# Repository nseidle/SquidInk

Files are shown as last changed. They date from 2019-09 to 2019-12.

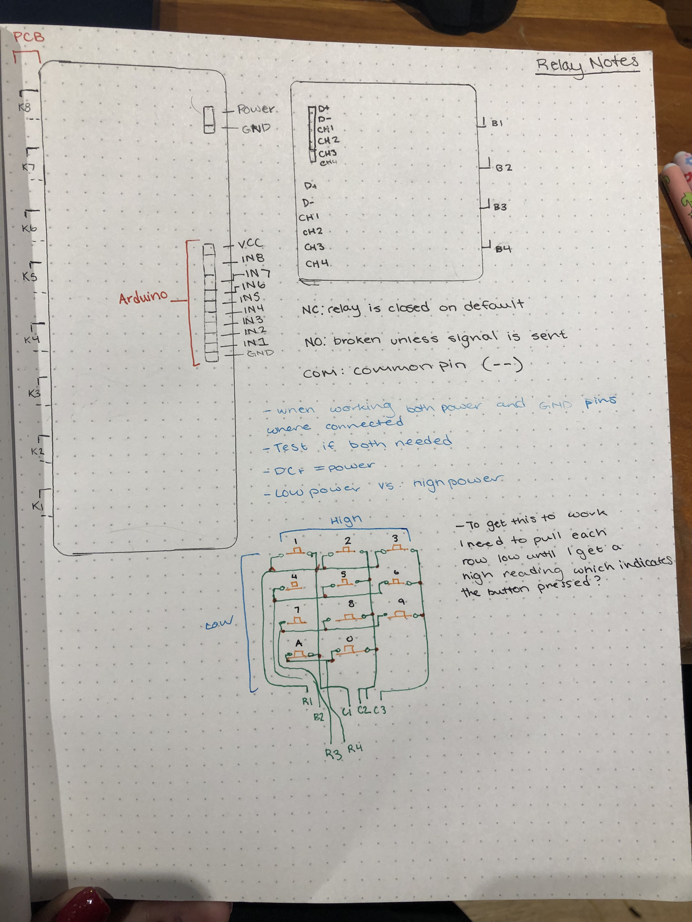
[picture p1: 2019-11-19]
relay-schematic/IMG_3992.jpg

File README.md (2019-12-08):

# SquidInk
Stalwart Keypad Safe Cracking Robot
Why are we doing this?
This project of attempting to crack into the stalwart safe is not only legal, it's teachable. We are being taught how to seek out the vulnerabilities in the keypad safe using various methods and contructing robots to do so. 

Here is the website with full documentation:

https://claire0sutton.wordpress.com/category/safecracking/

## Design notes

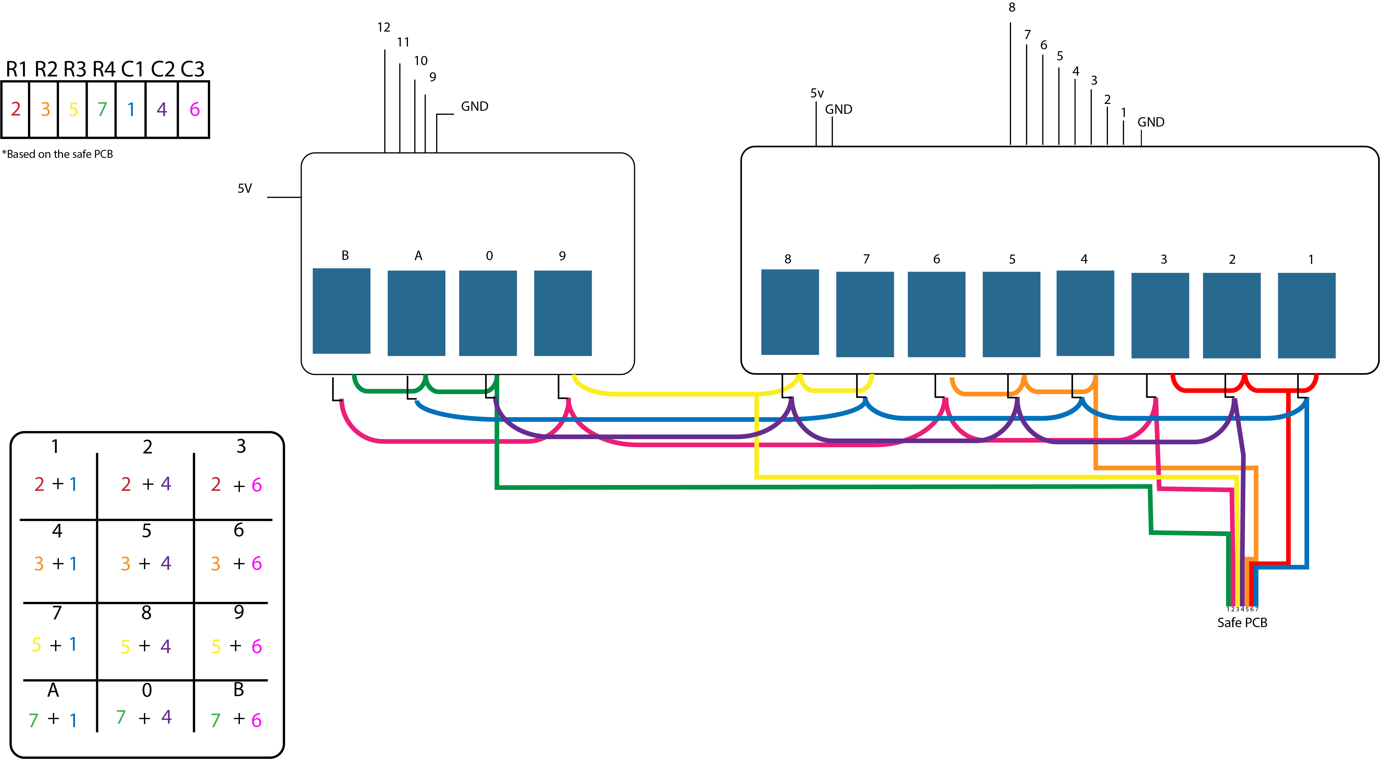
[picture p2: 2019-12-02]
relay-schematic/relay-switch-schematic.jpg

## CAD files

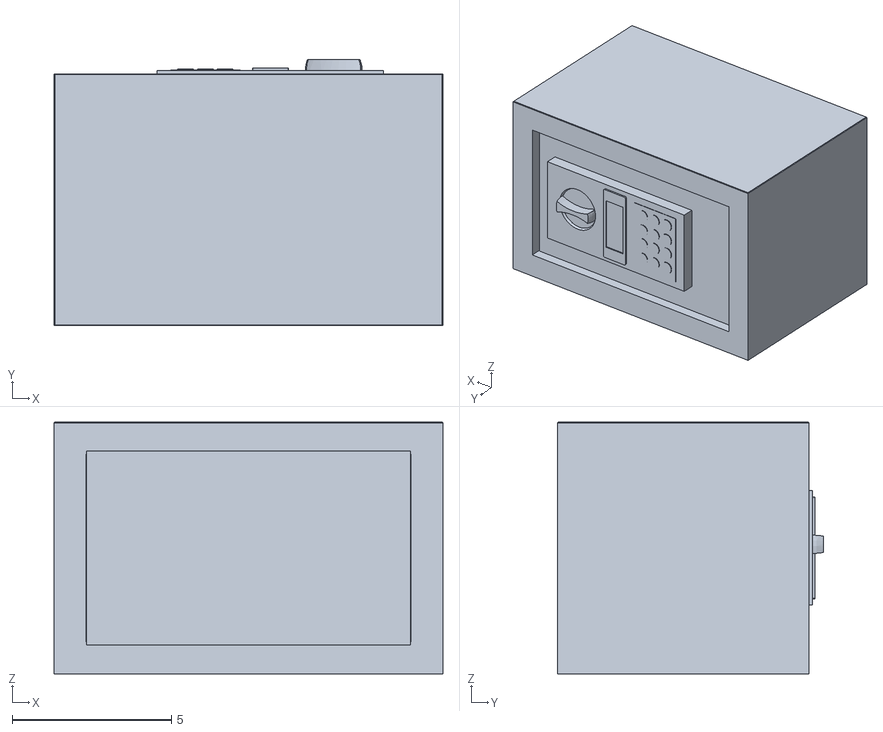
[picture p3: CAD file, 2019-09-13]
3D-models/safemodel.stl
12.2 x 8.39 x 7.90

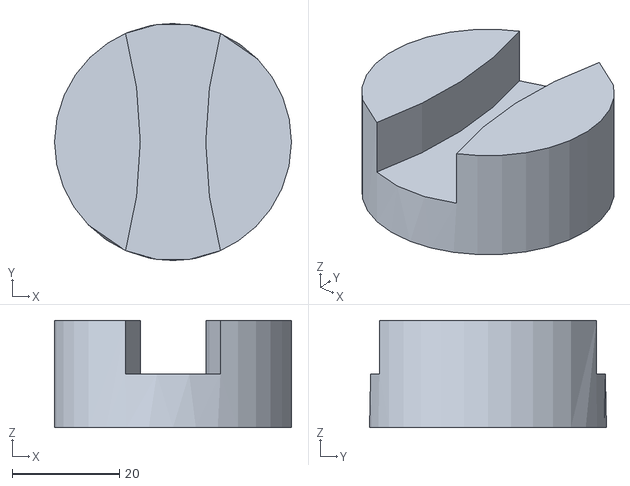
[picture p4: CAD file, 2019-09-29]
handle-puller-files/dial_coupler_bigger.stl
44.2 x 44.2 x 20.0

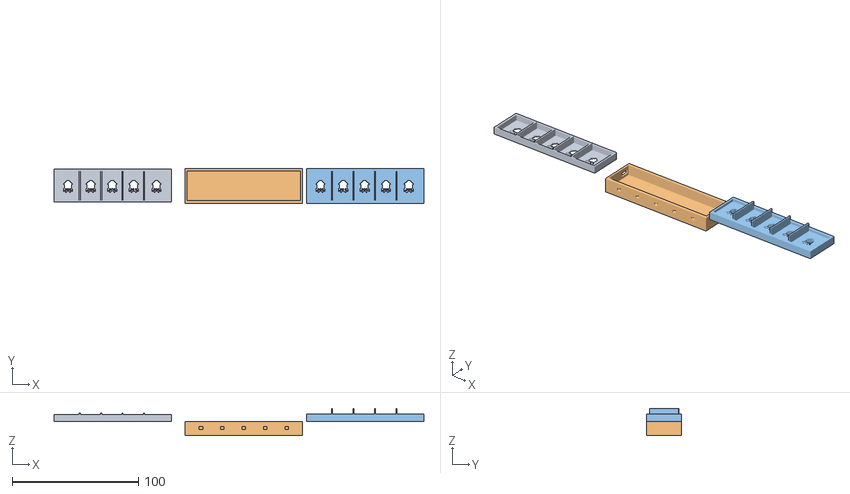
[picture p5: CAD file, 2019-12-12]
squid v10.obj
293.2 x 28.1 x 21.5

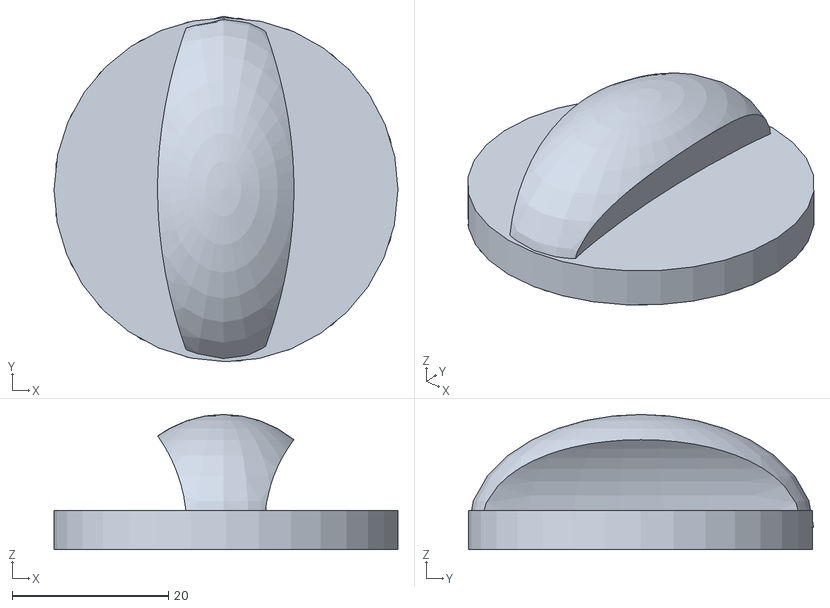
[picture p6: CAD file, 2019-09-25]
handle-puller-files/dial.stl
44.0 x 44.2 x 17.3

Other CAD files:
3D-models/The Safe v2.f3d
dial.3dm

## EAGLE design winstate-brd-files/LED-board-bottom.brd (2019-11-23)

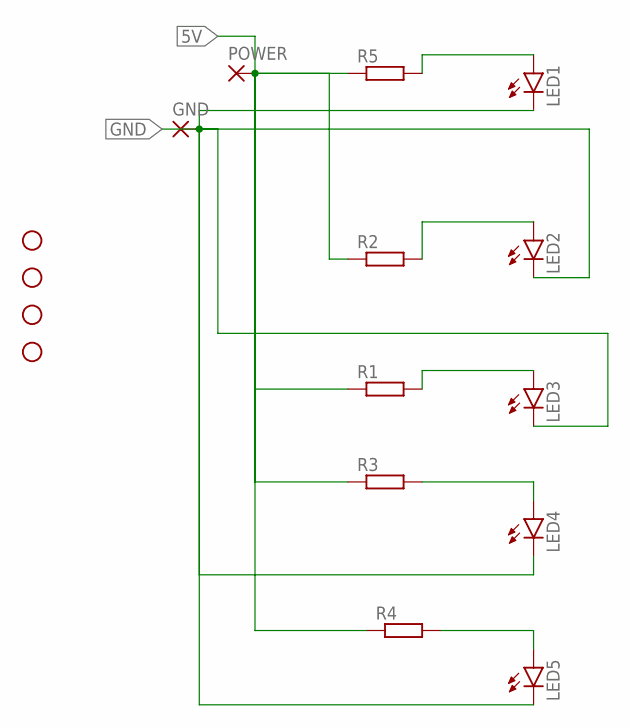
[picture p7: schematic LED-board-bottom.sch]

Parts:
GND: 1,6/0,8
H1, H2, H3, H4: STAND-OFF
LED1, LED2, LED3, LED4, LED5: LED3MM
POWER: 1,6/0,8
R1, R2, R3, R4, R5: R-EU_0207/10; 0207/10

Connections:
5V: POWER.1, R1.1, R2.1, R3.1, R4.1, R5.1
GND: GND.1, LED1.K (C), LED2.K (C), LED3.K (C), LED4.K (C), LED5.K (C)
unnamed: LED1.A, R5.2
unnamed: LED2.A, R2.2
unnamed: LED4.A, R3.2
unnamed: LED5.A, R4.2
unnamed: LED3.A, R1.2

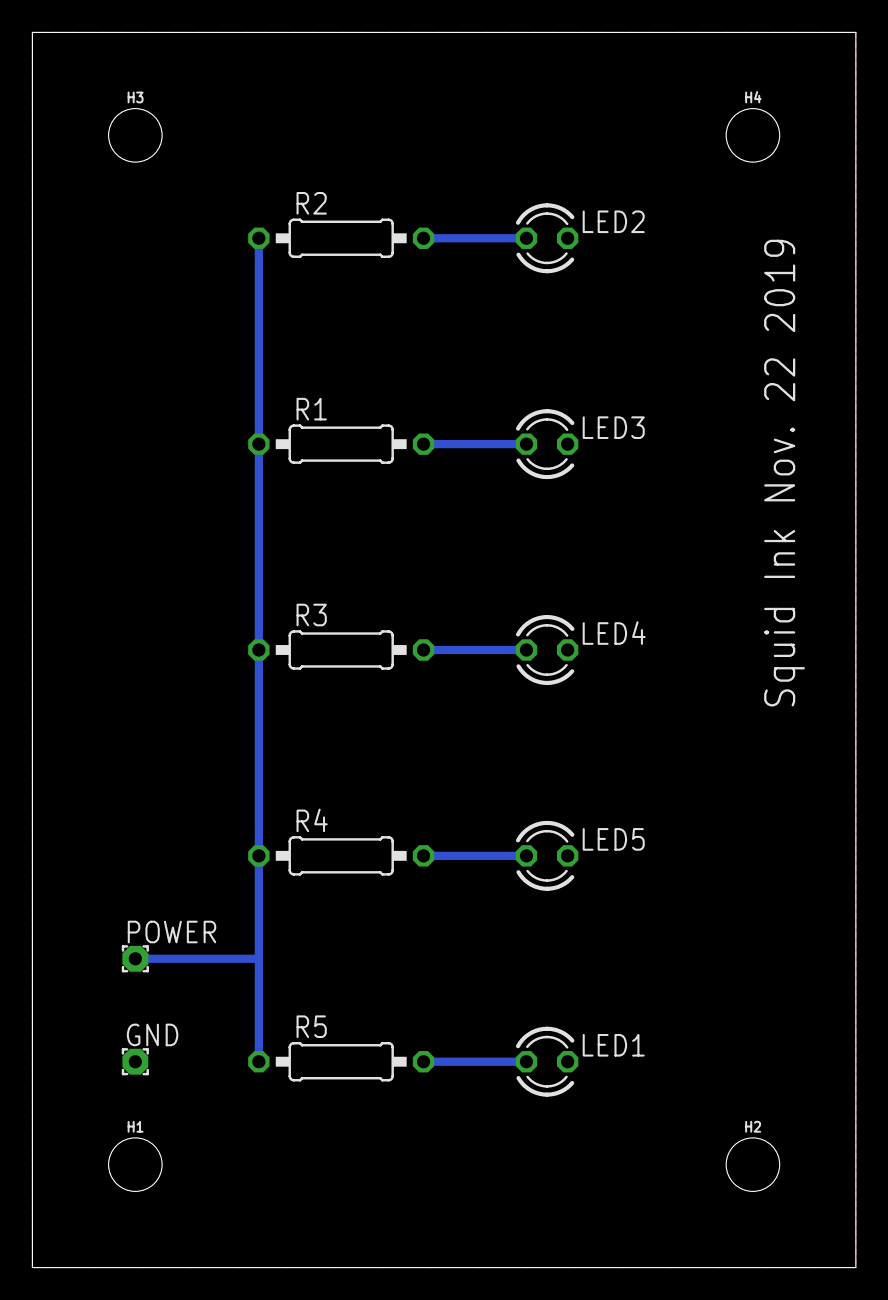
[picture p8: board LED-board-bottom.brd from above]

Board: 2 copper layers, 50.8 x 76.2 mm, 16 parts (0 on the bottom side), 7 nets.

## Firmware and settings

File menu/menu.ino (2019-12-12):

//created by Lili Cushing-Quevli
//modified: December 11th, 2019

//DESIGNED TO WORK WITH A 3 DIGIT CODE
//simulate pressing of buttons with a switch menu
//take user input and then properly press keys
//store winning value in EEPROM if using loop sequence function (can be unplugged from computer at this point)
//otherwise prints to serial monitor when winning code is found

#include <EEPROM.h>

//****RELAYS*****
int relay1 = 13;
int relay2 = 2;
int relay3 = 3;
int relay4 = 4;
int relay5 = 5;
int relay6 = 6;
int relay7 = 7;
int relay8 = 8;
int relay9 = 9;
int relay0 = 10;
int EnterA = 11;

int readResistor;

//*******LEDS**************
int LED1 = A5;
int LED2 = A4;
int LED3 = A3;
int LED4 = A2;
int LED5 = A1;




int photoResistor = A0;

int delayTime = 114;

//can go up to 3 codes before needing delay sequence called.
int timeOut = 1;

//used in the menu, typesetting
float reading = 0;
//array of all of manually entered values
float testedComboArray[2];
int randSelectCombo[1000];
//keep track of which value in the array is free :)
int increment = 0;
//entered code, set with returned value. If it's -1, something's wrong
int codeLength = 0;
//used in loopSequence function
int comboArray[3] = {0, 0, 0};
int winCodeArray[3] = {0, 0, 0};

//*****SERVO MOTOR********
//position of motor
//optional, currently commented out. For usage with the 3D printed handle cover and a servo motor (included in GH repo)
int pos = 0;
int servoPin = 12;

void setup()
{

  pinMode(relay1, OUTPUT);
  pinMode(relay2, OUTPUT);
  pinMode(relay3, OUTPUT);
  pinMode(relay4, OUTPUT);
  pinMode(relay5, OUTPUT);
  pinMode(relay6, OUTPUT);
  pinMode(relay7, OUTPUT);
  pinMode(relay8, OUTPUT);
  pinMode(relay9, OUTPUT);
  pinMode(relay0, OUTPUT);
  pinMode(EnterA, OUTPUT);

  //all relay switches are set to HIGH to be set LOW later when a button needs pressed
  digitalWrite(relay1, HIGH);
  digitalWrite(relay2, HIGH);
  digitalWrite(relay3, HIGH);
  digitalWrite(relay4, HIGH);
  digitalWrite(relay5, HIGH);
  digitalWrite(relay6, HIGH);
  digitalWrite(relay7, HIGH);
  digitalWrite(relay8, HIGH);
  digitalWrite(relay9, HIGH);
  digitalWrite(relay0, HIGH);
  digitalWrite(EnterA, HIGH);

  //fill the random combo array with values from 0-999
  int beginningIncrement = 0;
  for (int i = 0; i < 1000; i++)
  {
    randSelectCombo[i] = i;
  }


  Serial.begin(9600);

  //menu only prints once
  printMenu();


}

void loop() {

  //credit to Nathan Seidle for help with the code + lecture on serial.available
  while (Serial.available() > 0)
  {

    //if there's something to read, do something

    reading = Serial.read();

    if (reading == '\n') {
      Serial.print("\n");

    }

    //Serial.println(reading);
    //Didn't want to do ACII, so we do char reading instead
    if (reading == '1')
    {
      //sets EEMPROM code starting point
      startCombo();


    }

    else if (reading == '2')
    {
      //takes input from serial monitor and enters in correct buttons
      manualEnter();

    }

    else if (reading == '3')
    {
      //starts from EEPROM value, then increments in order, by going up one digit at a time
      loopSequence();

    }

    else if (reading == '4')
    {
      //set the combo
      startCombo();


    }

    else if (reading == '5')
    {
      //retrieve stored EEPROM win value once winState is triggered
      retrieveWinCode();

    }


    else
    {
      //don't do anything

    }


  }


}

void printMenu()
{
  Serial.println("Cracking a Keypad Safe, Choose an option");
  Serial.println("******When the safe combo is found, the squids will light up*******");
  Serial.println("1. Set starting code");
  Serial.println("2. Manually enter a code");
  Serial.println("3. Start loop sequence");
  Serial.println("4. Set Code Manually");
  Serial.println("5. Retrieve Win Code :)");


}


void manualEnter()
{
  delay(10);
  while (Serial.available() > 0)
  {

    //if there's something to read, take that number
    //save it in a value/ array
    //for now has an array of a large size, but could consider adding vector library, at the cost of memory
    //wait for carriage return

    while (Serial.available() > 0) {

      Serial.read();
      //clears out the buffer

    }

    Serial.println("ENTER THE COMBO (Do not use letters, please only 3 digits long)");
    while (Serial.available() == 0) {

      //Do nothing
    }
    while (Serial.available() > 0)
    {

      //if there's something to read, take that number
      //make it the length

      int testCombo = Serial.parseInt();
      Serial.print("The combo you've entered is: ");
      Serial.println(testCombo);

      //code citation
      //by Christop
      //source link: https://forum.arduino.cc/index.php?topic=307479.0
      //parses the full code entered and separates it into individual numbers
      unsigned n = testCombo;
      unsigned firstVal = (n / 100U) % 10;
      unsigned secondVal = (n / 10U) % 10;
      unsigned thirdVal = (n / 1U) % 10;

      //      Serial.println(firstVal);
      //      Serial.println(secondVal);
      //      Serial.println(thirdVal);
      //

      //press the numbers entered
      pressNumber(firstVal);
      pressNumber(secondVal);
      pressNumber(thirdVal);
      pressEnter();
      //Serial.println("Checking Winstate: ");
      bool testWin = winState();



      if (testWin == true)
      {
        Serial.print("Congratulations, you've entered the right combo. Your Combo is: ");
        Serial.print(firstVal);
        Serial.print(", ");
        Serial.print(secondVal);
        Serial.print(", ");
        Serial.println(thirdVal);

      }

      return;


    }




  }


}

void loopSequence()
{
  Serial.println("Sequence of all possible combos is about to begin");
  Serial.println("Combo array is:");

  bool found = 0;


  int addrTest = 0;
  int comboVal;

  //the 7th value is a boolean to determine if it was ever run (w/o a board reset) that way, we can fill in 
  //the values, if they exist
  if (EEPROM.read(7) == 1)
  {
    Serial.println("There was something previously stored here...");
    for (int j = 0; j < 3; j++)
    {
      comboVal = EEPROM.read(addrTest);
      addrTest += 2;

      Serial.print(comboVal, DEC);


      comboArray[j] = comboVal;

    }
  }
  Serial.print("\n");

  while (found == 0)
  {

    //by default, array is set to have all zeros
    //start with 0,0,0 and then increment the last value, going until the last value hits the tenth value
    //increment the second value and start the for loop again



    for (int i = comboArray[2]; i < 10; i++)
    {
      //call switch case menu to execute the pressing of the buttons


      pressNumber(comboArray[0]);

      pressNumber(comboArray[1]);

      pressNumber(i);



      pressEnter();
      Serial.print(comboArray[0]);
      Serial.print(",");
      Serial.print(comboArray[1]);
      Serial.print(",");
      Serial.println(i);

      addrTest = 0;

      for (int j = 0; j < 3; j++)
      {
        int writeCombo = 0;
        writeCombo = comboArray[j];
        EEPROM.write(addrTest, writeCombo);
        addrTest += 2;

      }



      if (winState())
      {
        Serial.println("WINNING CODE WAS:");

        Serial.print(comboArray[0]);
        Serial.print(",");
        Serial.print(comboArray[1]);
        Serial.print(",");
        Serial.println(i);
        int tracker = 8;

        //save in the secondary values of EEPROM, get in other function
        //int is 2 bytes, increment accordingly
        EEPROM.write(tracker, comboArray[0]);
        tracker += 2;
        EEPROM.write(tracker, comboArray[1]);
        tracker += 2;
        EEPROM.write(tracker, i);


        //        Serial.println("Congratulations, The correct combo has been found! Your Combo is: ");
        //        Serial.print(comboArray[0]);
        //        Serial.print(", ");
        //        Serial.print(comboArray[1]);
        //        Serial.print(", ");
        //        Serial.print(i);
        //        //turnHandle();
        //        Serial.println("Exiting function....");
        found = 1;
        break;
      }


      //every 3 combos, it requires a time out of 4 minutes and 46 seconds
      if (timeOut % 3 == 0)
      {
        stopSequence();
      }
      timeOut++;


    }

    //since the comboArray[2] was initially set with the EEPROM value, we now need to set it back to 0 when it starts the for loop again
    comboArray[2] = 0;

    //if the second combo does not have the value nine in it
    if (comboArray[1] < 9)
    {
      //move up one.
      //Example : instead of 0,0,0
      // it is now 0,1,[i]
      comboArray[1] += 1;


    }
    //on the 8th time, it will increment to 9 and then go through the for loop one last time with 9, then when it comes back
    //it is no longer less than 9, and will go to the next statement

    else
    {
      //if we have already gone through the second and third values with the current first value
      //and none worked, we increment the first value and try every possible value for the
      //second and third
      if (comboArray[1] >= 9)
      {
        comboArray[0] += 1;
        comboArray[1] = 0;
      }



    }


  }
  return;

}

void startCombo()
{
  delay(10);
  Serial.println("ENTER THE COMBO TO BEGIN LOOP (Do not use letters, please only 3 digits long)");
  while (Serial.available() > 0)
  {

    //if there's something to read, take that number
    //save it in a value/ array
    //for now has an array of a large size, but could consider adding vector library, at the cost of memory

    //wait for carriage return

    while (Serial.available() > 0) {

      Serial.read();
      //clears out the buffer

    }


    while (Serial.available() == 0) {

      //Do nothing
    }
    while (Serial.available() > 0)
    {

      //if there's something to read, take that number
      //make it the length

      int testCombo = Serial.parseInt();
      Serial.print("The combo you've entered is: ");
      Serial.println(testCombo);

      //code citation
      //by Christop
      //source link: https://forum.arduino.cc/index.php?topic=307479.0
      //parses the full code entered and separates it into individual numbers
      unsigned n = testCombo;
      unsigned firstVal = (n / 100U) % 10;
      unsigned secondVal = (n / 10U) % 10;
      unsigned thirdVal = (n / 1U) % 10;

      Serial.println("Setting the code....");
      int counting = 0;

      EEPROM.write(counting, firstVal );
      counting += 2;
      EEPROM.write(counting, secondVal);
      counting += 2;
      EEPROM.write(counting, thirdVal);

      EEPROM.write(7, 1);

      return;
    }
  }



}

void retrieveWinCode()
{
  Serial.println("Entered retrieve Win");

  int tracker = 8;
  int saver = 0;

  //get the EEPROM secondary values and then store in local array

  Serial.print("The Safes code is: ");
  saver = EEPROM.read(tracker);
  winCodeArray[0] = saver;


  tracker += 2;

  saver = EEPROM.read(tracker);
  winCodeArray[1] = saver;
  tracker += 2;

  saver = EEPROM.read(tracker);
  winCodeArray[2] = saver;

  Serial.print("YOUR WNNING CODE WAS: ");
  //print the array stored in EEPROM
  for (int i = 0; i < 3; i++)
  {

    Serial.print(winCodeArray[i]);

  }
  Serial.print("\n");



}

void resetCombo()
{
  delay(10);
  while (Serial.available() > 0)
  {

    //if there's something to read, take that number
    //save it in a value/ array
    //for now has an array of a large size, but could consider adding vector library, at the cost of memory
    //eeprom?
    //wait for carriage return

    while (Serial.available() > 0) {

      Serial.read();
      //clears out the buffer

    }

    Serial.println("Setting the Combo: Please enter your 3 digit Code you would like to set.");
    while (Serial.available() == 0) {

      //Do nothing
    }
    while (Serial.available() > 0)
    {

      //if there's something to read, take that number
      //make it the length

      int testCombo = Serial.parseInt();
      Serial.print("The combo you've entered is: ");
      Serial.println(testCombo);

      //code citation
      //by Christop
      //source link: https://forum.arduino.cc/index.php?topic=307479.0
      //parses the full code entered and separates it into individual numbers
      unsigned n = testCombo;
      unsigned firstVal = (n / 100U) % 10;
      unsigned secondVal = (n / 10U) % 10;
      unsigned thirdVal = (n / 1U) % 10;

      pressNumber(firstVal);
      pressNumber(secondVal);
      pressNumber(thirdVal);
      pressEnter();



      return;

    }
  }


}


//menu that takes a number passed into it and presses that number

void pressNumber( int var)
{
  switch (var)
  {
    case 0:
      pressZero();
      break;

    case 1:
      pressOne();
      break;

    case 2:
      pressTwo();
      break;

    case 3:
      pressThree();
      break;

    case 4:
      pressFour();
      break;

    case 5:
      pressFive();
      break;

    case 6:
      pressSix();
      break;

    case 7:
      pressSeven();
      break;

    case 8:
      pressEight();
      break;

    case 9:
      pressNine();
      break;


  }



}



bool winState()
{
  int counter = 0;
  //credit to Nathan Seidle for this code.
  //Wait for 1 second while the LED flashes (or doesn't)
  while (1)
  {
    counter++;
    if (counter > 1000)
    {
      //if it has been more than a second, then the light has not flashed and we exit
      return false;
    }
    delay(1);
    int temp = analogRead(photoResistor);
    //Serial.println(temp);
    if (temp > 100)
    {
      //Serial.println("GREEN");
      //if the photoresistor has registered the LED green light, then leave

      break;

    }

  }



  //Serial.println("CODE FOUND!!!!!!");

  //turn on LEDS
  digitalWrite(LED1, HIGH);
  delay(500);
  digitalWrite(LED2, HIGH);
  delay(500);
  digitalWrite(LED3, HIGH);
  delay(500);
  digitalWrite(LED4, HIGH);
  delay(500);
  digitalWrite(LED5, HIGH);





//if we broke out of the loop without returning false, it has turned green, code found
  return true;



}





void stopSequence()
{
  //delay for a four minutes and 46 seconds while the pcb times out
  delay(286500);

}



//************RELAY PRESS*******************
void pressOne()
{
  digitalWrite(relay1, LOW);
  delay(delayTime);
  digitalWrite(relay1, HIGH);
  delay(delayTime);



}
void pressTwo()
{
  digitalWrite(relay2, LOW);
  delay(delayTime);
  digitalWrite(relay2, HIGH);
  delay(delayTime);


}
void pressThree()
{
  digitalWrite(relay3, LOW);
  delay(delayTime);
  digitalWrite(relay3, HIGH);
  delay(delayTime);


}
void pressFour()
{
  digitalWrite(relay4, LOW);
  delay(delayTime);
  digitalWrite(relay4, HIGH);
  delay(delayTime);



}
void pressFive()
{
  digitalWrite(relay5, LOW);
  delay(delayTime);
  digitalWrite(relay5, HIGH);
  delay(delayTime);

}
void pressSix()
{
  digitalWrite(relay6, LOW);
  delay(delayTime);
  digitalWrite(relay6, HIGH);
  delay(delayTime);

}
void pressSeven()
{
  digitalWrite(relay7, LOW);
  delay(delayTime);
  digitalWrite(relay7, HIGH);
  delay(delayTime);
}
void pressEight()
{
  digitalWrite(relay8, LOW);
  delay(delayTime);
  digitalWrite(relay8, HIGH);
  delay(delayTime);

}
void pressNine()
{
  digitalWrite(relay9, LOW);
  delay(delayTime);
  digitalWrite(relay9, HIGH);
  delay(delayTime);

}
void pressZero()
{

  digitalWrite(relay0, LOW);
  delay(delayTime);
  digitalWrite(relay0, HIGH);
  delay(delayTime);

}

void pressEnter()
{
  digitalWrite(EnterA, LOW);
  delay(delayTime);
  digitalWrite(EnterA, HIGH);
  delay(10);


}

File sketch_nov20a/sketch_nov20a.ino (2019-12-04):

int relay1 = 13;
int relay5 = 5;
int relay9 = 9;
int Enter = 11;
int LED1 = A1;
int photoResistor = A0;
void setup() {
  // put your setup code here, to run once:
  pinMode(relay1, OUTPUT);
  pinMode(relay5, OUTPUT);
  pinMode(relay9, OUTPUT);
  pinMode(Enter, OUTPUT);
  pinMode(LED1, OUTPUT);
  pinMode(photoResistor, INPUT);
  digitalWrite(relay1, HIGH);
  digitalWrite(relay5, HIGH);
  digitalWrite(relay9, HIGH);
  digitalWrite(Enter, HIGH);
  Serial.begin(9600);

}

void loop() {
  digitalWrite(relay1, LOW);
  delay(1000);
  digitalWrite(relay1, HIGH);
  delay(1000);


  digitalWrite(relay5, LOW);
  delay(1000);
  digitalWrite(relay5, HIGH);
  delay(1000);

  digitalWrite(relay9, LOW);
  delay(1000);
  digitalWrite(relay9, HIGH);
  delay(1000);

  digitalWrite(Enter, LOW);
  delay(1000);
  digitalWrite(Enter, HIGH);
  delay(1000);
  
  int value = analogRead(photoResistor);
  Serial.println(value);

if(value>45){
  digitalWrite(LED1, HIGH);
  delay(10000);
  digitalWrite(LED1, LOW);
  }
  






}

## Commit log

2019-09-16 Add schematic for robot controller
    Does not yet work with photogate.
    [SparkFun_TensorFlow_Ambiq_Apollo3.sch]
2019-09-16 Removing example file class
    [SparkFun_TensorFlow_Ambiq_Apollo3.sch]
2019-09-16 Safe models- Lili CQ
    This is the 3D model of the safe. The following repository includes a .3dm (editable rhino file), and interactive stl (untextured but allows the user to rotate it and look at it), and JPEG images of 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
    Why are we doing this? For our class, this modeling is necessary to aid our group in thinking in terms of the dimensions of the safe for building a robot for it.
    [safemodel.stl]
2019-09-25 Dial Rough Draft
    Modeling the dial for coupler
    [dial.3dm, dial.stl]
2019-09-29 Motor Code
    Getting the motor to move forwards and backwards at varying speeds. Still working on the encoder
2019-09-29 dial coupler
    It is a good fit, but not as snug as it probably could be. There is no attachment for the servo motor, so it will have to wait until I can measure the attachment for it and then attach it to the coup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
    [dial_coupler_bigger.stl]
2019-10-08 combined coupler draft
2019-10-16 Create Keypad safe worst timing.xlsx
    [Keypad safe worst timing.xlsx]
2019-10-16 Safe longest time
    This is my calculations for the max case scenario.
    [Calculations for keypad safe.xlsx]
2019-10-17 Update Keypad safe worst timing.xlsx
    [Keypad safe worst timing.xlsx]
2019-11-17 Run_switch_menu
    Code that prints menu to serial monitor, asks for user input, and loops through all possibilities
    Work in progress
    Needs to be edited with switches plugged in + switch values
2019-11-18 Added Notes on Relay
2019-11-19 updated menu
    Can now take in input correctly. Now can parse the manually entered code and properly takes in data from the menu
    [menu.ino]
2019-11-20 menu w/relay switches
    menu with relay switch code in it
2019-11-20 Using Relays Example Code
2019-11-20 Relay Switch Example Code
    Used to test the Relay Switches
2019-11-20 Menu w/Relay switches
2019-11-23 LED board bottom layer
    should be functional, may edit later
    [LED-board-bottom.brd, LED-board-bottom.sch]
2019-12-02 Updated Menu
    tweaked variable names and fixed some comments
    [menu.ino]
2019-12-02 win-state-testing
    testing the LEDs
2019-12-02 schematic
    schematic for relay switches. Created by Claire Sutton
2019-12-02 Updated Menu
    Servo pin was wrong
    [menu.ino]
2019-12-04 Updated loops
    tested loop iteration and have made appropriate tweaks. Issue in printing repreatedly to the terminal. Perhaps an issue with the Serial reading going on in the menu
    [menu.ino, sketch_nov20a.ino]
2019-12-05 Update menu.ino
    Now has a more accurate timing, and can trigger win state properly. Added an extra function for setting the code when also pressing the button on the inside of the safe.
2019-12-06 Realistic Worst Case Time
    In progress worst case timing .xlsx
    [Calculations for keypad safe.xlsx]
2019-12-09 Organizing into files
    Making the github repo more organized
    [Calculations for keypad safe.xlsx, Keypad safe worst timing.xlsx, LED-board-bottom.brd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]
2019-12-11 finished menu
    Now has EEPROM features, retrieves wincode and stores it in EEPROM.
    Prints code to serial monitor, if desired, but can also run unattended and on a wall wart, not plugged into a computer
2019-12-11 Squid enclosure for LEDS
    [squid v10.obj]
2019-12-11 Worst Case Timing
    [New Time Calculations(12.11.19).xlsx]

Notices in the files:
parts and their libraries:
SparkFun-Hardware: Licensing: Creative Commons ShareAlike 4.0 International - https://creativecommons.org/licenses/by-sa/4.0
